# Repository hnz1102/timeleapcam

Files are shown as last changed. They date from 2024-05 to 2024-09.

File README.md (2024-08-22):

<div align="center">
  <h1><code>Time Leap Cam</code></h1>
  <p>
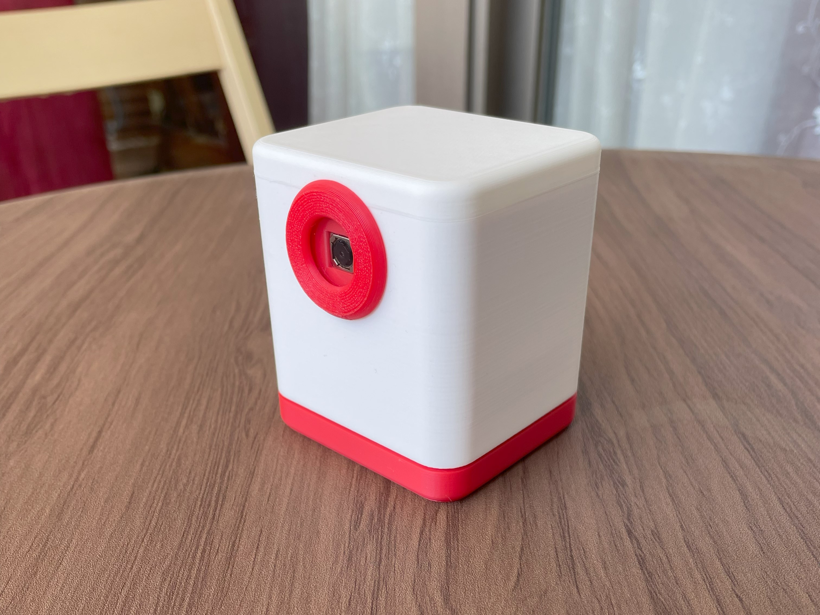
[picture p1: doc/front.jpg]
    
  </p>
</div>

# Time Leap Cam - Super Long Term Time-Lapse Camera and Monitoring by OpenAI

## Overview
The TIME LEAP CAM is an autofocus camera designed for long-duration time-lapse photography. Named for its ability to "leap" through time, this camera is ideal for monitoring over extended periods. It operates on battery power and features a DeepSleep mode to conserve energy when not actively shooting. Images are stored on a 64GB eMMC within one of eleven designated folders.

## What's New!
- 2024-08-12, If you want use on the XIAO ESP32S3 Sense module, please refer to the [XIAO_ESP32S3_SENSE branch](https://github.com/hnz1102/timeleapcam/tree/XIAO_ESP32S3_SENSE).
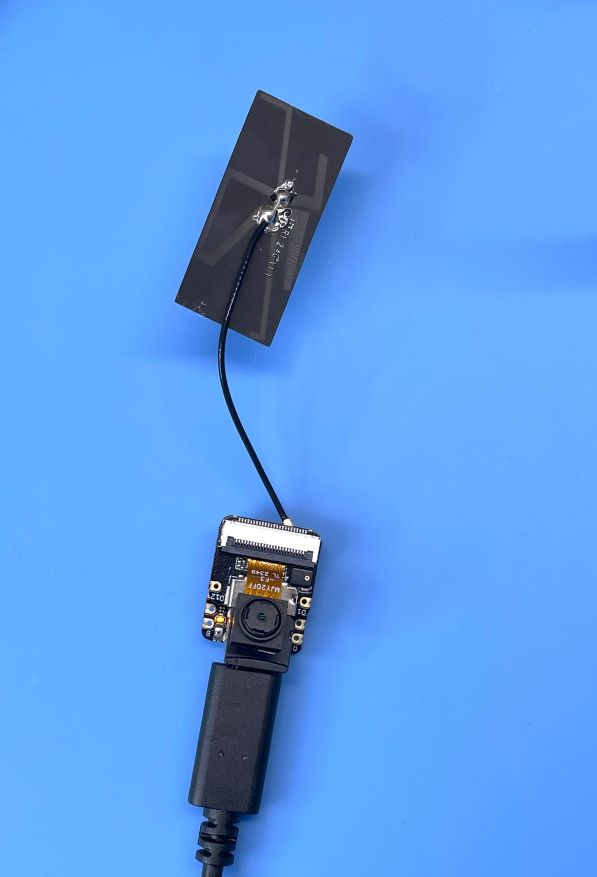
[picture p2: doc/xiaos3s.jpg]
XIAO_ESP32S3_SENSE


Update v0.3.3
- Improved the eMMC writing speed. The eMMC writing speed is improved by background writing. In the HD resolution, the writing speed is improved 28fps to 30fps. In the Full HD resolution, the writing speed is improved 6fps to 8fps. 
- JPEG quality can be set from 4 to 40. The default is 12. This value is high quality to set the value to 4. In the HD resolution, JPEG quality is set to less than 12, the writing speed is slower than 30fps. If you want to capture the image at 30fps, set the JPEG quality to 12 or more.
- If you want to direct write the image to the eMMC, set the 'Direct Write Mode' to checked. The image is directly written to the eMMC without the frame buffer. The writing speed is decreased. The default is unchecked.
- Changed the Allocate Unit Size to 32KB for the eMMC writing speed at the v0.3.3.

Update v0.3.2
- Add the 'System Temperature' to the status report. The temperature is measured by the internal temperature sensor of ESP32S3.
- Fixed the bug that when one-shot capture, the preview image is not displayed on the web.

Update v0.3.1
- Added the movie shooting function. The movie is created by combining the images taken at the specified cycle. 
 Capture Frames At Once (sec): The number of frames to capture at once. The default is 0, which means that the image is captured one by one. If you set it to 1, the image is captured during the 1 sec. If you set image resolution to VGA, the image is captured by 27 fps. HD is 15 - 27 fps. Full HD is 6 fps.
- Capture images are stored by appending the file. If you set to "Over Write Save", the image is overwritten. 
- Added the Open AI model 'GPT-4o mini' selection. The default is 'GPT-4o'. You can select the model from GPT-4o, GPT-4 Turbo, GPT-4o mini.
- If touch the button during 3 secs on the back, the camera starts the movie shooting. The movie shooting is stopped when the button is touched again.
- Improved the writing speed of the eMMC.
- Change the Report Interval: The default is 3600 sec. The report interval is changed to 3600 sec. The status report is sent to LINE when the specified cycle is reached.
- Camera interface is changed. Power Down, Reset pin is removed. In previous version, the power down pin and reset
pin are assigned by dumy GPIO pin. The 'esp-camera-rs' driver must be updated to the latest version.
- Fixed the bug that captured images are broken when the camera is in the DeepSleep mode. v0.3.1 is the stable version.
- Capturing clock is changed to 5MHz or 25MHz. The default is 5MHz when one image captured. When the movie is captured, the clock is changed to 25MHz.
- Changed the number of the frame buffer is 2. v0.3.0 set the number of the frame buffer to 3. But the eMMC writing speed is not enough to write the image to the eMMC. Since the eMMC writing speed is improved, the number of the frame buffer is changed to 2.
- Changed allocate_unit_size to 4096 for the eMMC writing speed at the v0.3.1.
- Fixed the bug that captured images are deleted when the camera is in the DeepSleep mode. v0.3.1 is fixed the bug.

Update v0.2.0
- Updated the UI for the configuration screen.
- Added the function to send a notification as status to LINE when the specified cycle is reached.
- Added the function to check the preview image on the web.
- Added images are uploaded to Cloudflare Images for private storage with signed URL.
- Added images are automatically deleted from the Cloudflare Images after 1 days.
- Added images can be downloaded as a compressed image from this camera on the web. (PC browser only)
- Added the function to check the remaining battery level on the web.
- Added the function to check the WiFi signal level on the web.
- Added the function to limit the time-lapse shooting time.
- Added the function to shoot when the camera touches the button during 3 secs on the back.

New Container Design
- The new container design is added for the camera
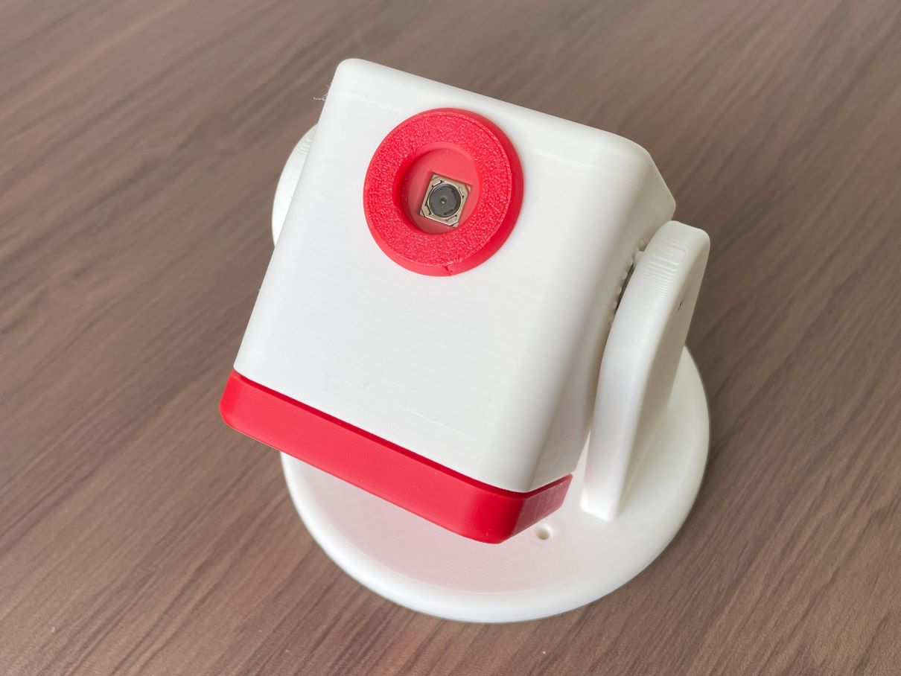
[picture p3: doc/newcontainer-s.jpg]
Container


## Features
- **Autofocus Capability**: Ensures clear images over long shooting intervals.
- **Energy Efficiency**: Utilizes DeepSleep mode for minimal power consumption (less than 440uA, 1.5mW).
- **Wireless Charging**: Supports Qi wireless charging and automatically stops charging when full.
- **Water Resistance**: Suitable for outdoor use with splash resistance.
- **Advanced Notifications**: Uses OpenAI's GPT-4o/GPT-4o mini for image recognition and sends notifications via LINE when specific conditions are met.
- **Natural Language Configuration**: Set notification conditions in multiple languages through a simple interface.
- **Touch-Activated Web Server**: Access settings via a browser with automatic return to sleep mode after 5 minutes of inactivity.
- **Time Synchronization**: Uses NTP for automatic time adjustment when connected to WiFi, with RTC to maintain time offline.

## Specification
- **Resolution**: Up to 2592x1944 (QSXGA)
- **Sensor**: OV5640 5M pixel sensor
- **SoC Module**: ESP32-S3-WROOM-1-N16R8 (160MHz, 512KB SRAM, 16MB Flash, 8MB PSRAM)
- **Battery**: 3.7V LiPo 1100mAh
- **Storage**: 64GB eMMC
- **Connectivity**: WiFi 2.4GHz
- **Charging**: Qi wireless charging compatible
- **Dimensions**: 78(W) x 79(H) x 68(D) mm Box

## Usage
To use the TIME LEAP CAM, place it on a Qi wireless charger to charge power. Configure the camera settings such as shooting interval, time, and resolution through a web browser connected via WiFi. The camera can be activated from sleep mode by touching the screw on the back, which launches the web server for configuration.

## Options
- **Folder Selection**: Choose from 11 different folders for storing images.
- **Image Resolution**: Selectable up to QSXGA (2592x1944).
- **Notification Conditions**: Set via natural language input on the configuration screen.

## Notes
- **Water Immersion**: The camera is not designed to withstand full submersion in water.
- **API Keys Required**: To use the image recognition and notification features, obtain API keys from OpenAI, CloudFlare Images, and LINE Messaging API.
- **Internet Connection**: Required for using advanced features like image recognition and notifications. Time-lapse functionality is available without WiFi.

For API keys and more information, visit:
- OpenAI API: [https://openai.com/index/openai-api/](https://openai.com/index/openai-api/)
- CloudFlare Images: [https://developers.cloudflare.com/images/about](https://developers.cloudflare.com/images/about)
- LINE Messaging API: [https://developers.line.biz/en/docs/messaging-api/](https://developers.line.biz/en/docs/messaging-api/)
# How to build from code and Install to the unit.

Using Ubuntu 22.04.3 LTS and ESP-IDF V5.2.1

## Prerequisites
Before proceeding with the installation, ensure that your system meets the following requirements:
- Operating System: Linux-based distribution
- Required Packages: git, python3, python3-pip, gcc, build-essential, curl, pkg-config, libudev-dev, libtinfo5, clang, libclang-dev, llvm-dev, udev, libssl-dev, python3.10-venv

## Installation Steps

### 1. System Update and Package Installation
Update your system and install the necessary packages using:
```bash
sudo apt update && sudo apt -y install git python3 python3-pip gcc build-essential curl pkg-config libudev-dev libtinfo5 clang libclang-dev llvm-dev udev libssl-dev python3.10-venv
```

### 2. Rust Installation
Install Rust programming language and Cargo package manager:
```bash
curl --proto '=https' --tlsv1.2 -sSf https://sh.rustup.rs | sh
```
After installation, activate Rust by sourcing the environment:
```bash
. "$HOME/.cargo/env"
```

### 3. Additional Tools Installation
Install the following Rust tools:
- ldproxy
- espup
- cargo-espflash

Use the following commands:
```bash
cargo install ldproxy
cargo install espup
cargo install cargo-espflash
```
2024-08-12, cargo-espflash can not be compiled.
If you have an error, use the following command.
```bash
cargo install cargo-binstall
cargo binstall cargo-espflash 
```

### 4. ESP Environment Setup
Run the following command to install and update the Espressif Rust ecosystem:
```bash
espup install
espup update
```
Set up environment variables:
```bash
. ./export-esp.sh
```

### 5. Udev Rules Configuration
Configure udev rules for device permissions:
```bash
sudo sh -c 'echo "SUBSYSTEMS==\"usb\", ATTRS{idVendor}==\"303a\", ATTRS{idProduct}==\"1001\", MODE=\"0666\"" > /etc/udev/rules.d/99-esp32.rules'
sudo udevadm control --reload-rules
sudo udevadm trigger
```

### 6. Clone Repository
Clone the TimeLeapCam repository:
```bash
git clone https://github.com/hnz1102/timeleapcam.git
cd timeleapcam/code/
```

### 7. Setting WiFi SSID, Password, etc.
Change the following the configuration file.
```bash
cfg.toml

[timeleapcam]
wifi_ssid = "<Your AP SSID>"  # Set your AP SSID
wifi_psk = "<Your AP Password>" # Set your AP Password
http_server = "" # NOT USED
resolution = "8"
track_id = "0"
timezone_offset = "9"
auto_capture = "false"
idle_in_sleep_time = "300"
duration = "0"
api_key = "<API KEY for openAI>" # Set your OpenAI API Key
model = "gpt-4o"
query_openai = "false"
query_prompt = "If heavy rain is expected in 30 minutes, please include a 'NOTICE' with the reason in your reply. If not, simply respond with 'NONE'. Heavy rain is defined as 30mm/h or more."
post_account = "<Your LINE Account ID>" # Set your LINE Account ID
post_access_token = "<Access Token for LINE Message>" # Set your LINE Access Token
storage_account = "<Your Cloudflare Account ID>" # Set your Cloudflare Account ID
storage_access_token = "<Your Cloudflare Access Token>" # Set your Cloudflare Access Token
storage_signed_key = "<Your Cloudflare Image Signed Key>" # Set your Cloudflare Image Signed Key
post_message_trigger = "NOTICE"
autofocus_once = "true"
status_report = "false"
status_report_interval = "3600"
post_interval = "3600"
leap_day = "-1"
leap_hour = "-1"
leap_minute = "-1"
capture_frames_at_once = "0"
overwrite_saved = "false"
```

### 8. Build and Flash
Build the project and flash it to your device:
```bash
cargo build --release
cargo espflash flash --release --monitor
```
At the first boot, the device will format the eMMC and create the necessary folders. This process may take a few minutes.

## Schematic, PCB Gabar and Container 3D Data

There is a Schematic data in the hardware directory including 3D printing data. 

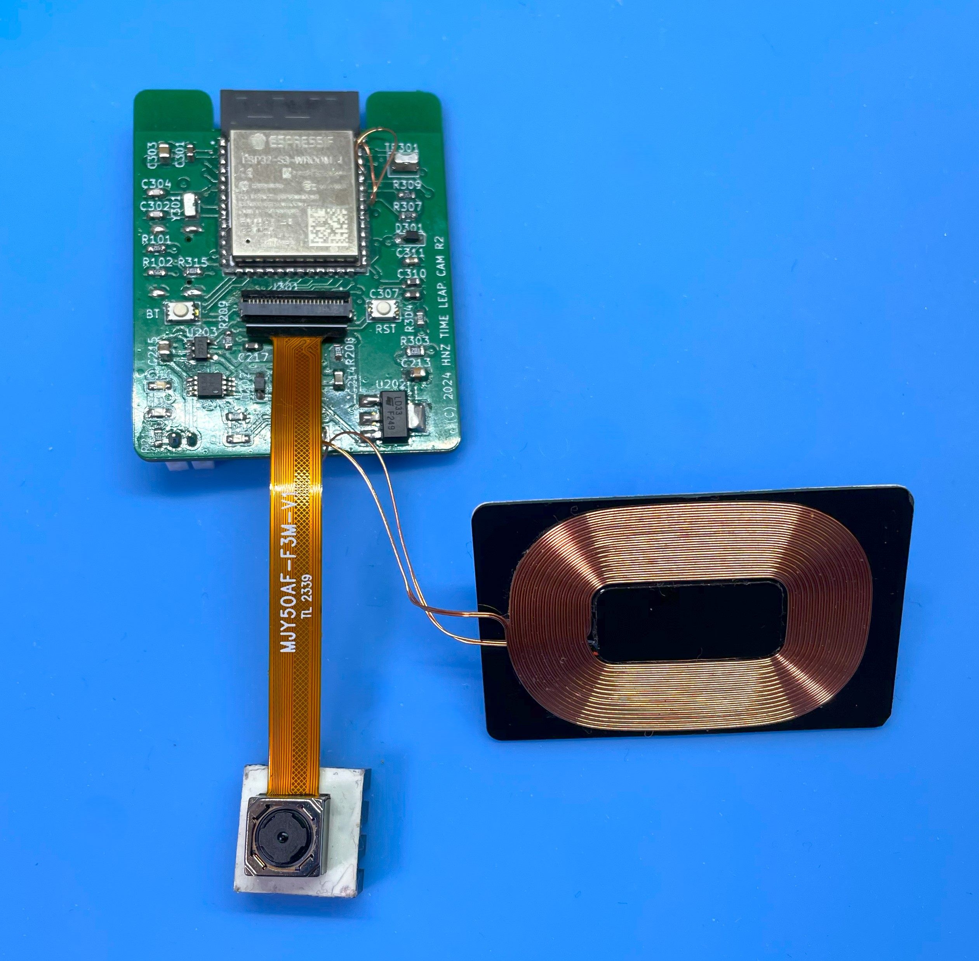
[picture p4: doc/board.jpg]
board


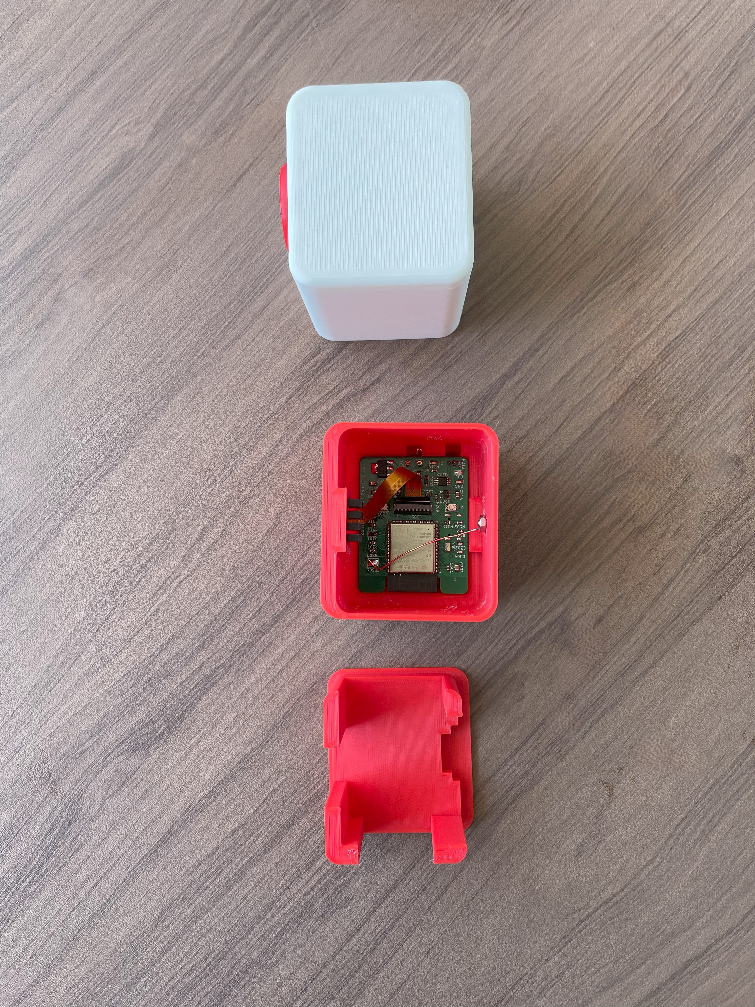
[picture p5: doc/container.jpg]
container


### New Cover and Base for the Camera
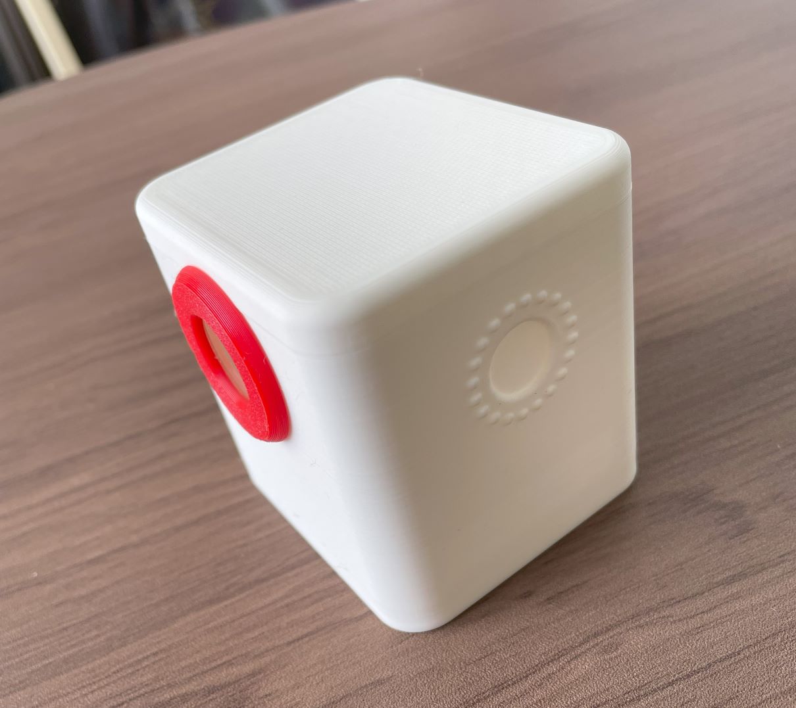
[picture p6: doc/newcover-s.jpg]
New-Cover


Base for the camera is also available for 3D printing. base-v14.stl is the latest version.
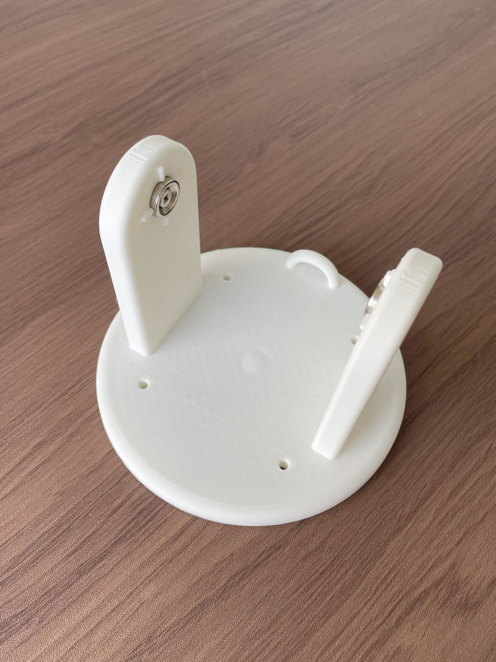
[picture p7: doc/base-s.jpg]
base


## Troubleshooting
- **Permission Issues**: Ensure udev rules are set correctly and you have the necessary permissions to access the device.
- **Build Errors**: Check that all dependencies are installed correctly. If errors persist, try cleaning the project with `cargo clean` and rebuild.

## LICENSE
This source code is licensed under MIT. Other Hardware Schematic documents are licensed under CC-BY-SA V4.0.

This project uses the following libraries and resources:
  
https://github.com/jlocash/esp-camera-rs

https://github.com/0015/ESP32-OV5640-AF

These libraries are licensed under each library's respective licenses.

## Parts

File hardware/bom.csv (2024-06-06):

Reference | Value | Datasheet | Footprint | Qty | DNP | digikey
C201,C207,C210 | 22nF/25V | ~ | Capacitor_SMD:C_0603_1608Metric | 3 |  | 490-17777-1-ND
C202,C208,C209 | 0.01uF/25V | ~ | Capacitor_SMD:C_0603_1608Metric | 3 |  | 311-1085-1-ND
C203,C217 | 0.1uF/25V | ~ | Capacitor_SMD:C_0603_1608Metric | 2 |  | 311-1343-1-ND
C204,C216,C218,C305,C306,C308,C309,C312,C313 | 1uF | ~ | Capacitor_SMD:C_0805_2012Metric | 9 |  | 311-1457-1-ND
C205 | 2000pF/25V | ~ | Capacitor_SMD:C_0603_1608Metric | 1 |  | 490-1458-1-ND
C206,C211 | 0.47uF/25V | ~ | Capacitor_SMD:C_0603_1608Metric | 2 |  | 445-5144-1-ND
C212,C301,C307,C310,C314,C315 | 0.1uF | ~ | Capacitor_SMD:C_0603_1608Metric | 6 |  | 311-1343-1-ND
C213,C303 | 10uF | ~ | Capacitor_SMD:C_0805_2012Metric | 2 |  | 1276-1096-1-ND
C214,C219 | 22uF | ~ | Capacitor_SMD:C_0805_2012Metric | 2 |  | 311-1903-1-ND
C215 | 4.7uF | ~ | Capacitor_SMD:C_0805_2012Metric | 1 |  | 1276-1244-1-ND
C302,C304 | 16pF | ~ | Capacitor_SMD:C_0603_1608Metric | 2 |  | 1292-1490-1-ND
C311 | 2.2uF | ~ | Capacitor_SMD:C_0603_1608Metric | 1 |  | 1276-1040-1-ND
D201,D203 | LED RED | ~ | LED_SMD:LED_0603_1608Metric_Pad1.05x0.95mm_HandSolder | 2 |  | 3147-B1931URO-20D000114U1930CT-ND
D202,D301 | NSR0340HT1G | https://www.onsemi.com/pub/Collateral/NSR0340H-D.PDF | Diode_SMD:D_SOD-323_HandSoldering | 2 |  | NSR0340HT1GOSCT-ND
D204 | LED GREEN | ~ | LED_SMD:LED_0603_1608Metric_Pad1.05x0.95mm_HandSolder | 1 |  | 3147-B1931NG--20D001114U1930CT-ND
FB101 | MH2029-601Y | ~ | Inductor_SMD:L_0805_2012Metric | 1 |  | MH2029-601YCT-ND
J101 | USB4105-GF-A | https://www.usb.org/sites/default/files/documents/usb_type-c.zip | tbctl:USB_C_5077CR-16-SMC2-BK-TR | 1 |  | 2073-USB4105-GF-ACT-ND
J201 | LiPo BATTERY | ~ | Connector_JST:JST_PH_B2B-PH-K_1x02_P2.00mm_Vertical | 1 |  | 455-1704-ND
J301 | FH34SRJ-24S-0.5SH50 | FH34SRJ-24S-0.5SH50 | tbctl:HRS_FH34SRJ-24S-0.5SH_50_ | 1 |  | 26-FH34SRJ-24S-0.5SH(50)CT-ND
L101 | WR483265-15F5-G | ~ | tbctl:PinHole_1x02_P4.5mm_Vertical | 1 |  | 445-16090-ND
Q201,Q202,Q203,Q301 | IRF7606TRPBF | http://www.irf.com/product-info/datasheets/data/irf7606pbf.pdf | Package_SO:MSOP-8_3x3mm_P0.65mm | 4 |  | IRF7606TRPBFCT-ND
R101,R102 | 5.1K | ~ | Resistor_SMD:R_0603_1608Metric | 2 |  | 311-5.1KGRCT-ND
R202,R303 | 1K | ~ | Resistor_SMD:R_0603_1608Metric | 2 |  | 311-1.00KHRCT-ND
R203,R208,R301,R302,R304,R308,R320,R321 | 10K | ~ | Resistor_SMD:R_0603_1608Metric | 8 |  | 13-RC0603JR-1010KLCT-ND
R204 | 110 1% | ~ | Resistor_SMD:R_0603_1608Metric | 1 |  | 13-RC0603FR-13110RLCT-ND
R207 | 150 1% | ~ | Resistor_SMD:R_0603_1608Metric | 1 |  | 13-RC0603FR-10150RLCT-ND
R209 | 2K | ~ | Resistor_SMD:R_0603_1608Metric | 1 |  | 311-2.0KGRCT-ND
R210,R310,R311,R312,R313,R314,R315,R316,R317,R318,R319 | 100K | ~ | Resistor_SMD:R_0603_1608Metric | 11 |  | 311-100KGRCT-ND
R211,R212 | 330 | ~ | Resistor_SMD:R_0603_1608Metric | 2 |  | 13-RC0603JR-13330RLCT-ND
R305,R306 | 51K 1% | ~ | Resistor_SMD:R_0603_1608Metric | 2 |  | 311-51.0KHRCT-ND
R307,R309 | 4.7K | ~ | Resistor_SMD:R_0603_1608Metric | 2 |  | 311-4.70KHRCT-ND
SW301,SW302 | 3.5x2.6 Tact SW |  | tbctl:WS-TASV SMT Tact Switch | 2 |  | 732-435151014824CT-ND
TP301 | TOUCHSW | ~ | tbctl:TestPoint_Pad_3.2x1.6mm | 1 |  | 2019-RCWCTECT-ND
U201 | BQ51013BRHLR | BQ51013BRHLR | RHL20_2P05X3P05 | 1 |  | 296-38885-1-ND
U202 | LDL1117S33TR_SOT223 | http://www.st.com/st-web-ui/static/active/en/resource/technical/document/datasheet/CD00000544.pdf | Package_TO_SOT_SMD:SOT-223-3_TabPin2 | 1 |  | 497-17239-1-ND
U203 | MCP73831-2-OT | http://ww1.microchip.com/downloads/en/DeviceDoc/20001984g.pdf | Package_TO_SOT_SMD:SOT-23-5 | 1 |  | MCP73831T-2ACI/OTCT-ND
U301 | ESP32-S3-WROOM-1-N16R8 | ESP32-S3-WROOM-1-N16R2 | ESP32-S3-WROOM-1_EXP | 1 |  | 1965-ESP32-S3-WROOM-1-N16R8CT-ND
U302 | MCP1700T-1502E/TT | http://ww1.microchip.com/downloads/en/DeviceDoc/20001826D.pdf | Package_TO_SOT_SMD:SOT-23 | 1 |  | MCP1700T-1502E/TTCT-ND
U303 | MCP1700T-2802E/TT | http://ww1.microchip.com/downloads/en/DeviceDoc/20001826D.pdf | Package_TO_SOT_SMD:SOT-23 | 1 |  | MCP1700T-2802E/TTCT-ND
U304 | FEMC064G-M11 |  | tbctl:EM32VSUKN FPGA153 | 1 |  | 3052-FEMC064G-M11-ND
Y301 | 32.7680KHz | ~ | Crystal:Crystal_SMD_3215-2Pin_3.2x1.5mm | 1 |  | 2151-RT3215-32.768-12.5-TRCT-ND

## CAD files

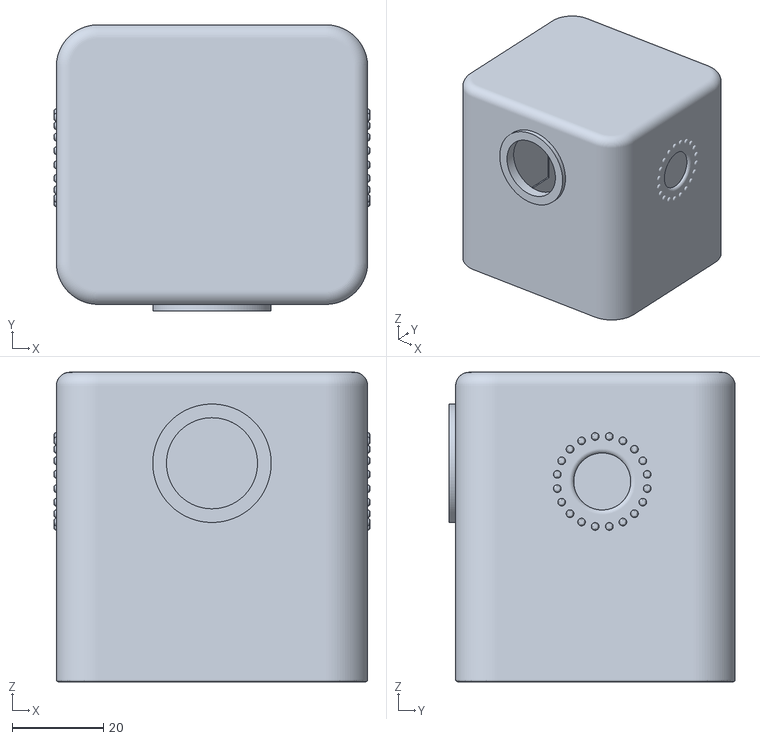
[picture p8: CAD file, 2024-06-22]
hardware/top-v15.stl
69.4 x 62.9 x 68.0

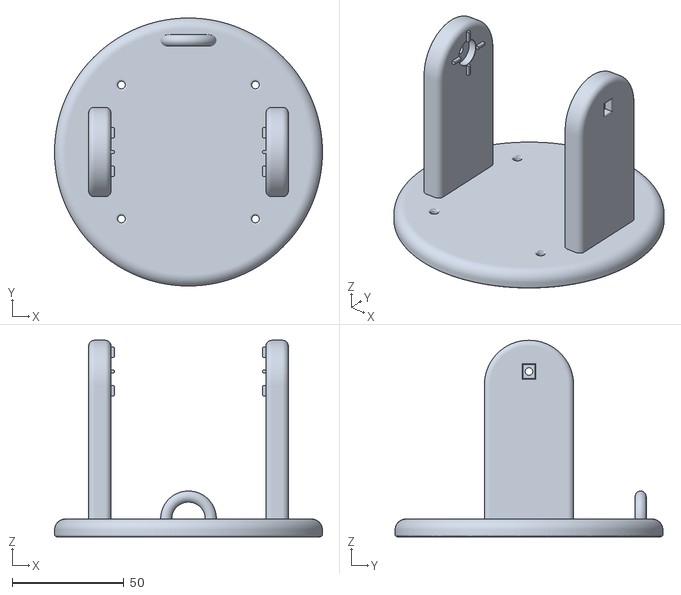
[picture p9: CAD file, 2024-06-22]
hardware/base-v14.stl
120.0 x 120.0 x 88.0

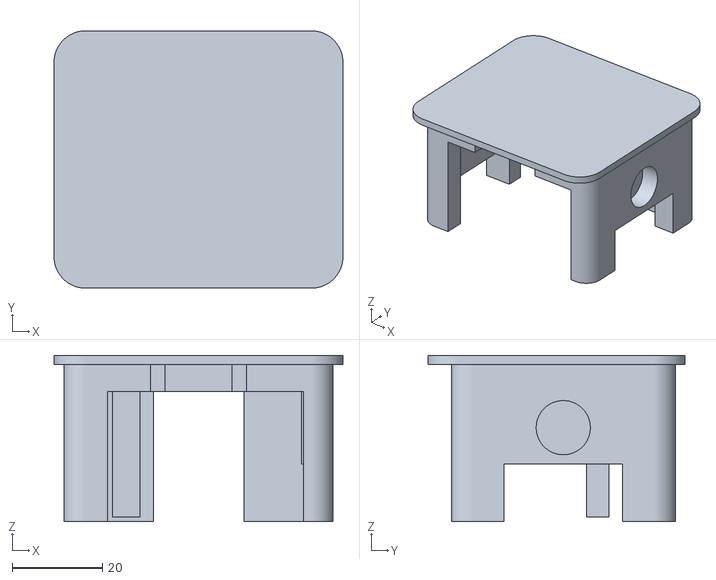
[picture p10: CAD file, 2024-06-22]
hardware/cap-v11.stl
64.0 x 57.0 x 36.8

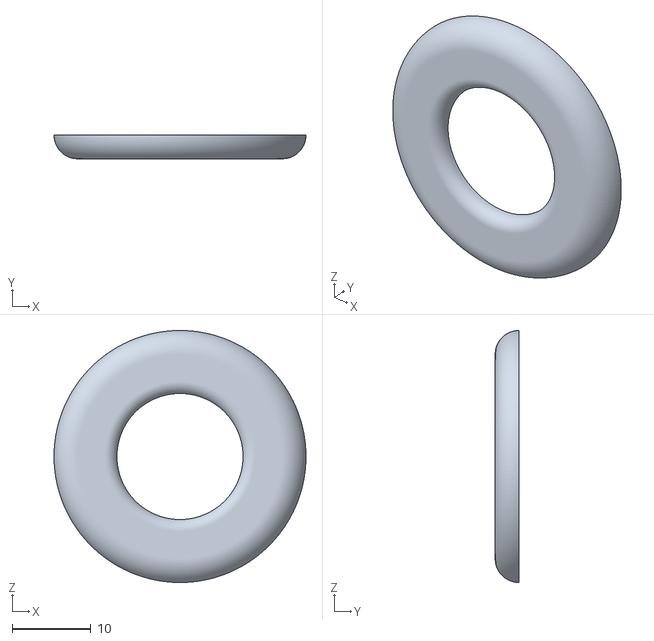
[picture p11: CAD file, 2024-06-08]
hardware/lensecap-v9.stl
32.0 x 3.00 x 32.0

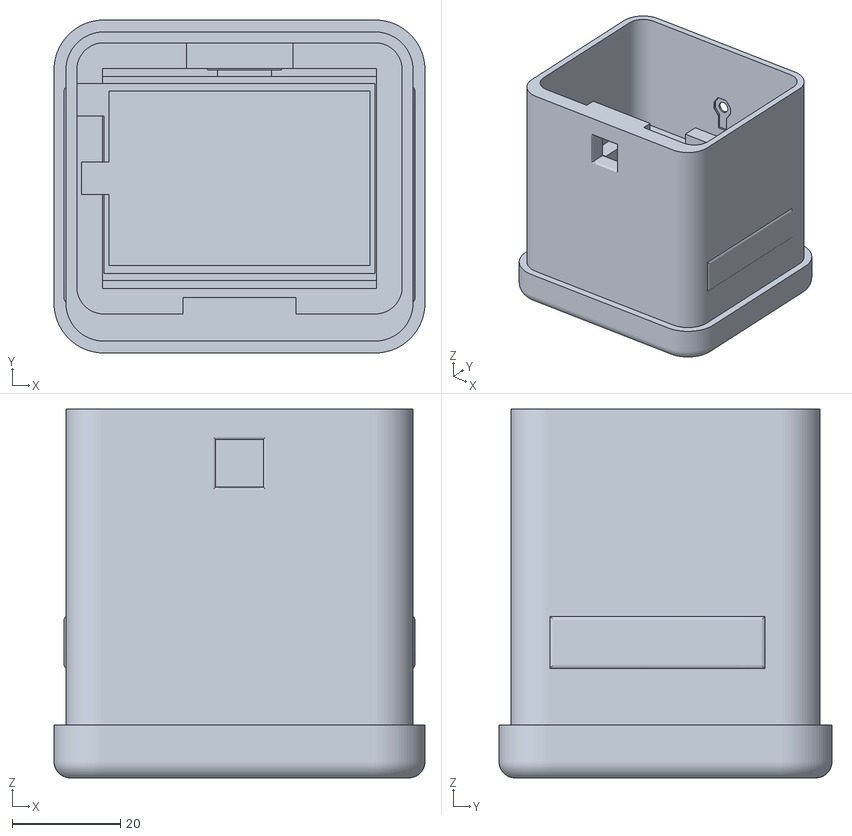
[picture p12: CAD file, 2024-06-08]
hardware/bottom-v9.stl
68.4 x 61.4 x 68.0

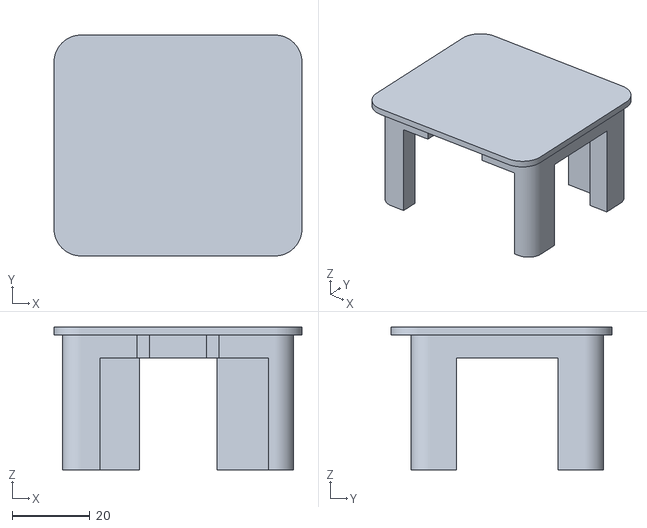
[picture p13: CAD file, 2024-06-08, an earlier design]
hardware/cap-v9.stl
64.0 x 57.0 x 36.8

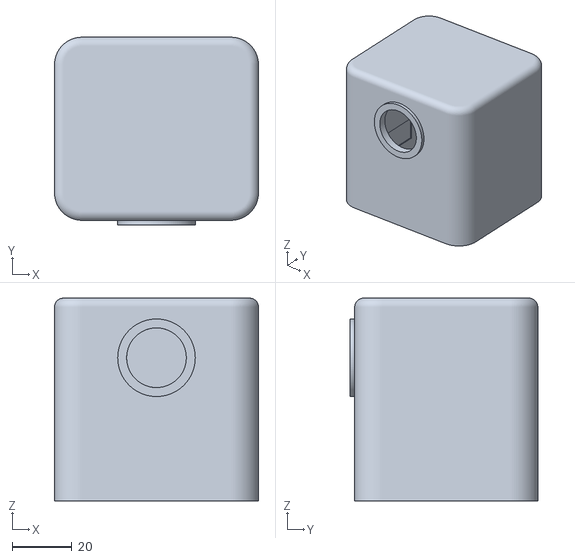
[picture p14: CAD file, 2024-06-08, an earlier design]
hardware/top-v9.stl
68.4 x 62.9 x 68.0

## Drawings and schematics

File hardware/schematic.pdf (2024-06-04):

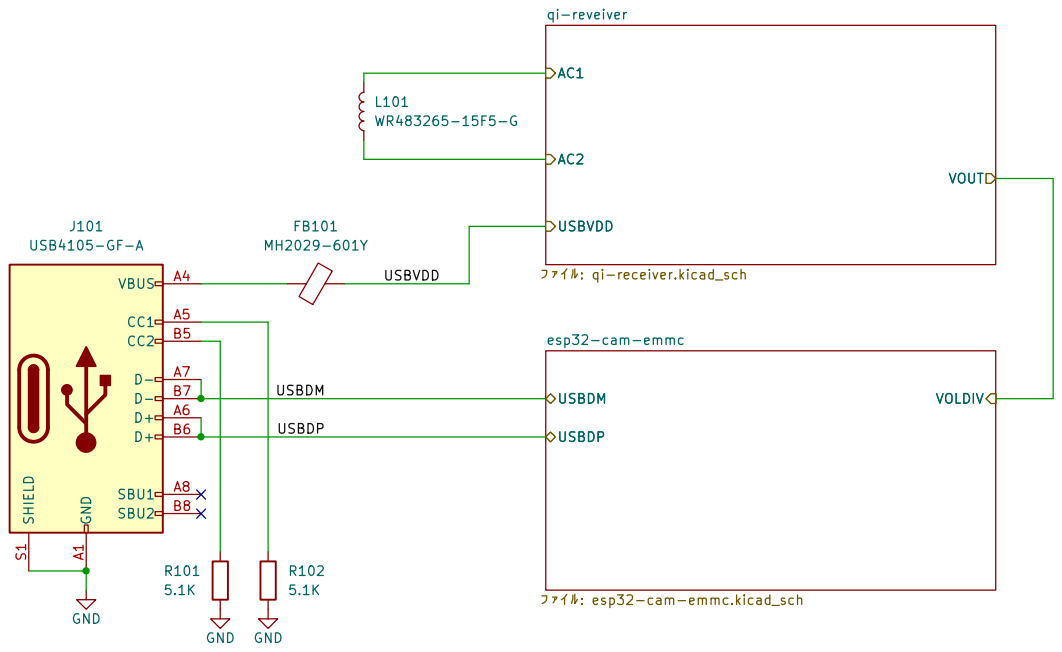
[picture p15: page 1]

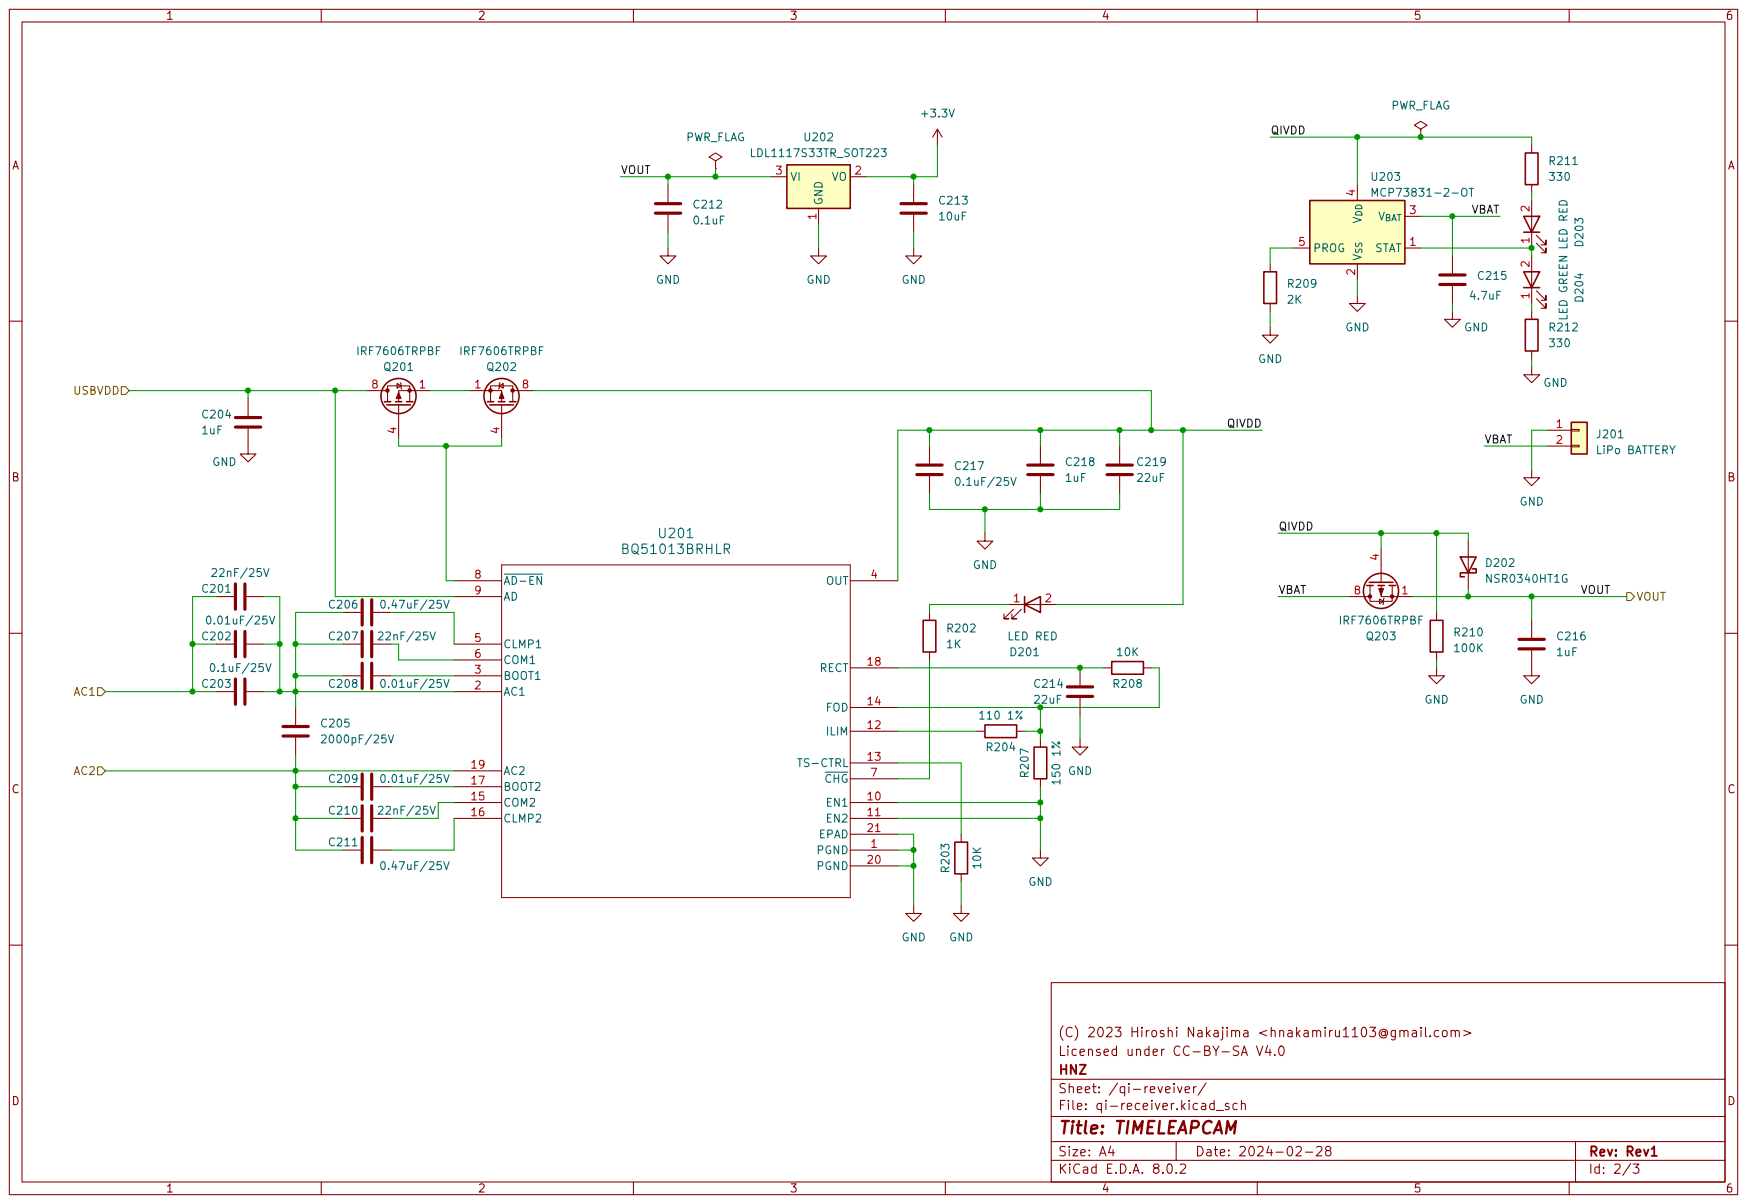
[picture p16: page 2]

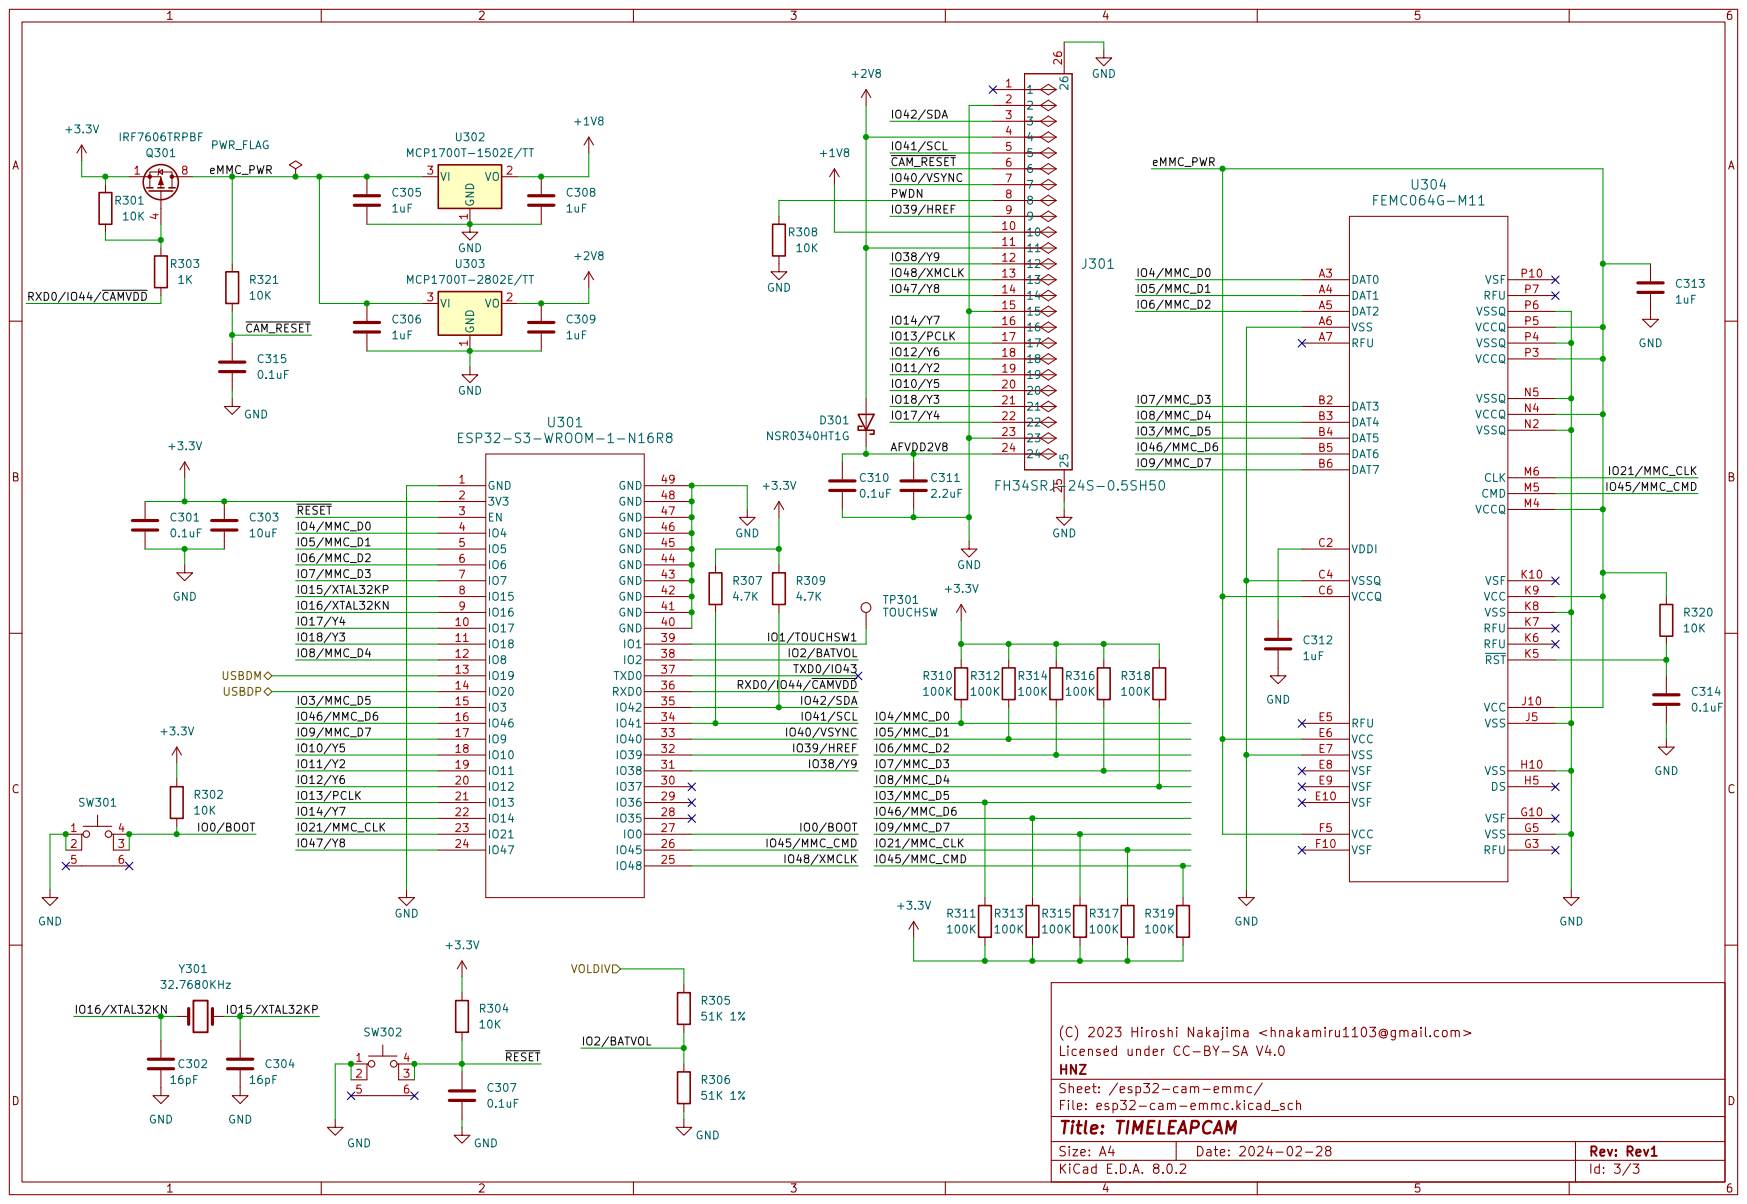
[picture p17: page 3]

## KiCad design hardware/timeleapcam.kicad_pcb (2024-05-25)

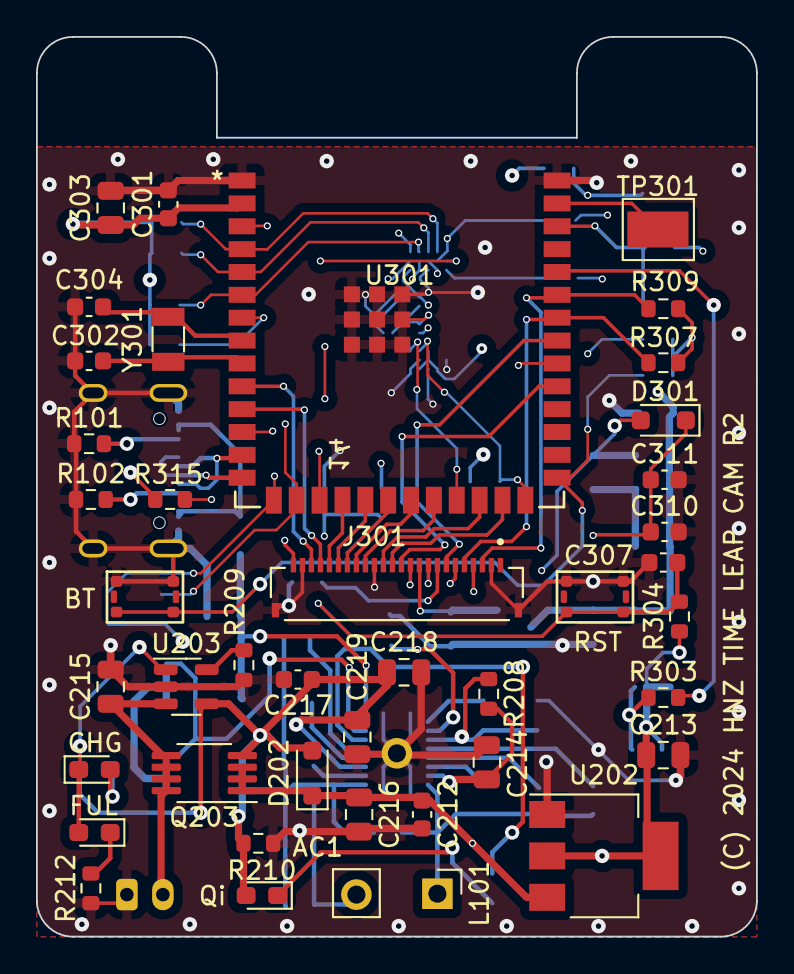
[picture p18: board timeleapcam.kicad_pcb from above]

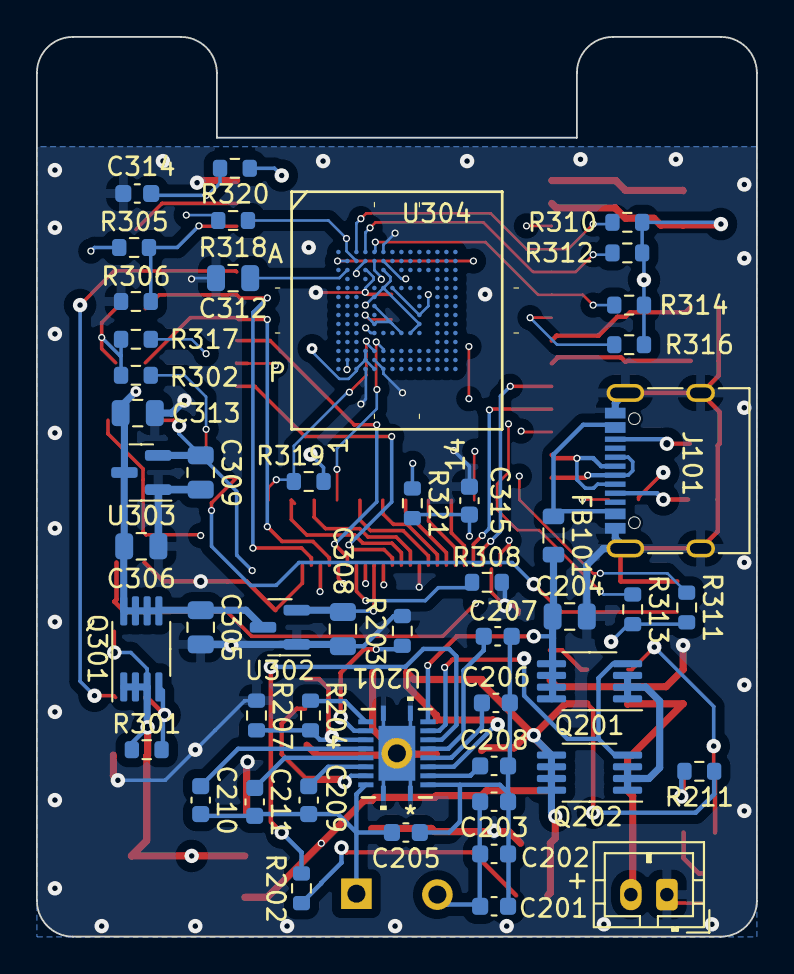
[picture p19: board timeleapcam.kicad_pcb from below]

Board: 4 copper layers, 40.0 x 50.0 mm, 91 parts (50 on the bottom side), 72 nets.

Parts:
C201, C207, C210: 22nF/25V; C_0603_1608Metric
C202, C208, C209: 0.01uF/25V; C_0603_1608Metric
C203, C217: 0.1uF/25V; C_0603_1608Metric
C204, C216, C218, C305, C306, C308, C309, C312, C313: 1uF; C_0805_2012Metric
C205: 2000pF/25V; C_0603_1608Metric
C206, C211: 0.47uF/25V; C_0603_1608Metric
C212, C301, C307, C310, C314, C315: 0.1uF; C_0603_1608Metric
C213, C303: 10uF; C_0805_2012Metric
C214, C219: 22uF; C_0805_2012Metric
C215: 4.7uF; C_0805_2012Metric
C302, C304: 16pF; C_0603_1608Metric
C311: 2.2uF; C_0603_1608Metric
D201, D203: LED RED; LED_0603_1608Metric_Pad1.05x0.95mm_HandSolder
D202, D301: NSR0340HT1G; D_SOD-323_HandSoldering
D204: LED GREEN; LED_0603_1608Metric_Pad1.05x0.95mm_HandSolder
FB101: MH2029-601Y; L_0805_2012Metric
J101: USB4105-GF-A; USB_C_5077CR-16-SMC2-BK-TR
J201: LiPo BATTERY; JST_PH_B2B-PH-K_1x02_P2.00mm_Vertical
J301: FH34SRJ-24S-0.5SH50; HRS_FH34SRJ-24S-0.5SH_50_
L101: WR483265-15F5-G; PinHole_1x02_P4.5mm_Vertical
Q201, Q202, Q203, Q301: IRF7606TRPBF; MSOP-8_3x3mm_P0.65mm
R101, R102: 5.1K; R_0603_1608Metric
R202, R303: 1K; R_0603_1608Metric
R203, R208, R301, R302, R304, R308, R310, R311, R312, R313, R314, R315, R316, R317, R318, R319, R320, R321: 10K; R_0603_1608Metric
R204: 110 1%; R_0603_1608Metric
R207: 150 1%; R_0603_1608Metric
R209: 2K; R_0603_1608Metric
R210: 100K; R_0603_1608Metric
R211, R212: 330; R_0603_1608Metric
R305, R306: 51K 1%; R_0603_1608Metric
R307, R309: 4.7K; R_0603_1608Metric
SW301, SW302: 3.5x2.6 Tact SW; WS-TASV SMT Tact Switch
TP301: TOUCHSW; TestPoint_Pad_3.2x1.6mm
U201: BQ51013BRHLR; RHL20_2P05X3P05
U202: LD1117S33TR_SOT223; SOT-223-3_TabPin2
U203: MCP73831-2-OT; SOT-23-5
U301: ESP32-S3-WROOM-1-N16R8; ESP32-S3-WROOM-1_EXP
U302: MCP1700T-1802E/TT; SOT-23
U303: MCP1700T-2802E/TT; SOT-23
U304: FEMC064G-M11; EM32VSUKN FPGA153
Y301: 32.7680KHz; Crystal_SMD_3215-2Pin_3.2x1.5mm

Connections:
+1V8: C308.1, J301.10, U302.2 (VO)
+2V8: C309.1, D301.2 (A), J301.4, J301.11, U303.2 (VO)
+3.3V: C213.1, C301.1, C303.1, Q301.1 (S), Q301.2 (S), Q301.3 (S), R301.1, R302.1, R304.1, R307.1, R309.1, R310.1, R311.2, R312.1, R313.2, R314.1, R315.2, R316.1, R317.2, R318.1, R319.2, U202.2 (VO), U301.2 (3V3)
/USBDM: J101.A7 (D-), J101.B7 (D-), U301.13 (IO19)
/USBDP: J101.A6 (D+), J101.B6 (D+), U301.14 (IO20)
/USBVDD: C204.1, FB101.2, Q201.5 (D), Q201.6 (D), Q201.7 (D), Q201.8 (D), U201.9 (AD)
/esp32-cam-emmc/AFVDD2V8: C310.1, C311.1, D301.1 (K), J301.24
/esp32-cam-emmc/IO0/BOOT: R302.2, SW301.3 (K), SW301.4 (A), U301.27 (IO0)
/esp32-cam-emmc/IO1/TOUCHSW1: TP301.1, U301.39 (IO1)
/esp32-cam-emmc/IO2/BATVOL: R305.2, R306.1, U301.38 (IO2)
/esp32-cam-emmc/IO3/MMC_D5: R311.1, U301.15 (IO3), U304.B4 (DAT5)
/esp32-cam-emmc/IO4/MMC_D0: R310.2, U301.4 (IO4), U304.A3 (DAT0)
/esp32-cam-emmc/IO5/MMC_D1: R312.2, U301.5 (IO5), U304.A4 (DAT1)
/esp32-cam-emmc/IO6/MMC_D2: R314.2, U301.6 (IO6), U304.A5 (DAT2)
/esp32-cam-emmc/IO7/MMC_D3: R316.2, U301.7 (IO7), U304.B2 (DAT3)
/esp32-cam-emmc/IO8/MMC_D4: R318.2, U301.12 (IO8), U304.B3 (DAT4)
/esp32-cam-emmc/IO9/MMC_D7: R315.1, U301.17 (IO9), U304.B6 (DAT7)
/esp32-cam-emmc/IO10/Y5: J301.20, U301.18 (IO10)
/esp32-cam-emmc/IO11/Y2: J301.19, U301.19 (IO11)
/esp32-cam-emmc/IO12/Y6: J301.18, U301.20 (IO12)
/esp32-cam-emmc/IO13/PCLK: J301.17, U301.21 (IO13)
/esp32-cam-emmc/IO14/Y7: J301.16, U301.22 (IO14)
/esp32-cam-emmc/IO15/XTAL32KP: C304.1, U301.8 (IO15), Y301.2
/esp32-cam-emmc/IO16/XTAL32KN: C302.1, U301.9 (IO16), Y301.1
/esp32-cam-emmc/IO17/Y4: J301.22, U301.10 (IO17)
/esp32-cam-emmc/IO18/Y3: J301.21, U301.11 (IO18)
/esp32-cam-emmc/IO21/MMC_CLK: R317.1, U301.23 (IO21), U304.M6 (CLK)
/esp32-cam-emmc/IO38/Y9: J301.12, U301.31 (IO38)
/esp32-cam-emmc/IO39/HREF: J301.9, U301.32 (IO39)
/esp32-cam-emmc/IO40/VSYNC: J301.7, U301.33 (IO40)
/esp32-cam-emmc/IO41/SCL: J301.5, R307.2, U301.34 (IO41)
/esp32-cam-emmc/IO42/SDA: J301.3, R309.2, U301.35 (IO42)
/esp32-cam-emmc/IO45/MMC_CMD: R319.1, U301.26 (IO45), U304.M5 (CMD)
/esp32-cam-emmc/IO46/MMC_D6: R313.1, U301.16 (IO46), U304.B5 (DAT6)
/esp32-cam-emmc/IO47/Y8: J301.14, U301.24 (IO47)
/esp32-cam-emmc/IO48/XMCLK: J301.13, U301.25 (IO48)
/esp32-cam-emmc/PWDN: J301.8, R308.1
/esp32-cam-emmc/RXD0/IO44/~CAMVDD: R303.2, U301.36 (RXD0)
/esp32-cam-emmc/eMMC_PWR: C305.1, C306.1, C313.1, Q301.5 (D), Q301.6 (D), Q301.7 (D), Q301.8 (D), R320.1, R321.1, U302.3 (VI), U303.3 (VI), U304.C6 (VCCQ), U304.E6 (VCC), U304.F5 (VCC), U304.J10 (VCC), U304.K9 (VCC), U304.M4 (VCCQ), U304.N4 (VCCQ), U304.P3 (VCCQ), U304.P5 (VCCQ)
/esp32-cam-emmc/~CAM_RESET: C315.1, J301.6, R321.2
/esp32-cam-emmc/~RESET: C307.1, R304.2, SW302.3 (K), SW302.4 (A), U301.3 (EN)
/qi-reveiver/AC1: C201.2, C202.2, C203.2, L101.2
/qi-reveiver/AC2: C205.2, C209.2, C210.2, C211.2, L101.1, U201.19 (AC2)
/qi-reveiver/QIVDD: C217.1, C218.1, C219.1, D201.2 (A), D202.2 (A), Q202.5 (D), Q202.6 (D), Q202.7 (D), Q202.8 (D), Q203.4 (G), R210.1, R211.1, U201.4 (OUT), U203.4 (V_{DD})
/qi-reveiver/VBAT: C215.1, J201.2, Q203.5 (D), Q203.6 (D), Q203.7 (D), Q203.8 (D), U203.3 (V_{BAT})
/qi-reveiver/VOUT: C212.1, C216.1, D202.1 (K), Q203.1 (S), Q203.2 (S), Q203.3 (S), R305.1, U202.3 (VI)
GND: C204.2, C212.2, C213.2, C214.2, C215.2, C216.2, C217.2, C218.2, C219.2, C301.2, C302.2, C303.2, C304.2, C305.2, C306.2, C307.2, C308.2, C309.2, C310.2, C311.2, C312.2, C313.2, C314.2, C315.2, J101.A1 (GND), J101.A12 (GND), J101.B1 (GND), J101.B12 (GND), J101.S1 (SHIELD), J201.1, J301.2, J301.15, J301.23, J301.25, J301.26, R101.1, R102.1, R203.1, R207.1, R209.2, R210.2, R212.2, R306.2, R308.2, SW301.1, SW301.2, SW302.1, SW302.2, U201.1 (PGND), U201.10 (EN1), U201.11 (EN2), U201.20 (PGND), U201.21 (EPAD), U202.1 (GND), U203.2 (V_{SS}), U301.1 (GND), U301.40 (GND), U301.41 (GND), U301.42 (GND), U301.43 (GND), U301.44 (GND), U301.45 (GND), U301.46 (GND), U301.47 (GND), U301.48 (GND), U301.49 (GND), U302.1 (GND), U303.1 (GND), U304.A6 (VSS), U304.C4 (VSSQ), U304.E7 (VSS), U304.G5 (VSS), U304.H10 (VSS), U304.J5 (VSS), U304.K8 (VSS), U304.N2 (VSSQ), U304.N5 (VSSQ), U304.P4 (VSSQ), U304.P6 (VSSQ)
unnamed: D201.1 (K), R202.1
unnamed: D203.2 (A), R211.2
unnamed: D203.1 (K), D204.2 (A), U203.1 (STAT)
unnamed: D204.1 (K), R212.1
unnamed: FB101.1, J101.A4 (VBUS), J101.A9 (VBUS), J101.B4 (VBUS), J101.B9 (VBUS)
unnamed: J101.A5 (CC1), R102.2
unnamed: J101.B5 (CC2), R101.2
unnamed: Q201.4 (G), Q202.4 (G), U201.8 (~AD-EN)
unnamed: Q201.1 (S), Q201.2 (S), Q201.3 (S), Q202.1 (S), Q202.2 (S), Q202.3 (S)
unnamed: Q301.4 (G), R301.2, R303.1
unnamed: C201.1, C202.1, C203.1, C205.1, C206.2, C207.2, C208.2, U201.2 (AC1)
unnamed: C208.1, U201.3 (BOOT1)
unnamed: C209.1, U201.17 (BOOT2)
unnamed: C206.1, U201.5 (CLMP1)
unnamed: C211.1, U201.16 (CLMP2)
unnamed: C207.1, U201.6 (COM1)
unnamed: C210.1, U201.15 (COM2)
unnamed: R204.1, R207.2, R208.1, U201.14 (FOD)
unnamed: R204.2, U201.12 (ILIM)
unnamed: C214.1, R208.2, U201.18 (RECT)
unnamed: R203.2, U201.13 (TS-CTRL)
unnamed: R202.2, U201.7 (~CHG)
unnamed: R209.1, U203.5 (PROG)
unnamed: C312.1, U304.C2 (VDDI)
unnamed: C314.1, R320.2, U304.K5 (~RST)

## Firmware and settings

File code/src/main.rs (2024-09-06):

#![allow(dead_code, unused_imports)]

use anyhow;
use std::{thread, time::Duration};
use esp_camera_rs::Camera;
use esp_idf_hal::peripherals::Peripherals;
use esp_idf_hal::gpio::{PinDriver, Gpio2};
use esp_idf_svc::wifi::EspWifi;
use esp_idf_sys::camera;
use log::info;
use std::net::Ipv4Addr;

use esp_idf_svc::nvs::{EspNvsPartition, NvsDefault, EspNvs, NvsPartitionId};
use esp_idf_svc::sntp::{EspSntp, SyncStatus, SntpConf, OperatingMode, SyncMode};
use esp_idf_hal::adc::{config::Config as AdcConfig, AdcChannelDriver, AdcDriver};
use std::time::{SystemTime, UNIX_EPOCH};
use chrono::{DateTime, Utc};
use chrono::{Local, Duration as ChronoDuration, FixedOffset, NaiveDate, Datelike, Timelike};

mod wifi;
mod capture;
mod autofocus;
mod emmc;
mod imagefiles;
mod server;
mod config;
mod touchpad;
mod monitoring;

use touchpad::{TouchPad, KeyEvent, Key};
use config::ConfigData;
use capture::Capture;
use emmc::EMMCHost;
use server::LeapTime;
use monitoring::Monitoring;

#[derive(PartialEq)]
enum SleepMode {
    SleepModeLight,
    SleepModeDeep,
}

const MAX_NVS_STR_SIZE : usize = 3072;

#[link_section = ".rtc.data"]
static mut IMAGE_COUNT_ID: u32 = 0;

#[link_section = ".rtc.data"]
static mut DEEP_SLEEP_AUTO_CAPTURE: bool = false;

#[link_section = ".rtc.data"]
static mut NEXT_CAPTURE_TIME: u64 = 0;

#[link_section = ".rtc.data"]
static mut DURATION_TIME: u32 = 0;

#[link_section = ".rtc.data"]
static mut CURRENT_RESOLUTION: u32 = 0;

#[link_section = ".rtc.data"]
static mut CURRENT_TRACK_ID: u32 = 0;

#[link_section = ".rtc.data"]
static mut LAST_CAPTURE_TIME: u64 = 0;

#[link_section = ".rtc.data"]
static mut LAST_POSTED_TIME: u64 = 0;

#[link_section = ".rtc.data"]
static mut CAPTURE_START_TIME: u64 = 0;

#[link_section = ".rtc.data"]
static mut CAPTURE_END_TIME: u64 = 0;

#[link_section = ".rtc.data"]
static mut LAST_STATUS_POSTED_TIME: u64 = 0;

fn main() -> anyhow::Result<()> {
    esp_idf_svc::sys::link_patches();
    esp_idf_svc::log::EspLogger::initialize_default();

    // Peripherals Initialize
    let peripherals = Peripherals::take().unwrap();

    // eMMC and Camera Power On (low active)
    let mut emmc_cam_power = PinDriver::output(peripherals.pins.gpio44).unwrap();
    emmc_cam_power.set_low().expect("Set emmc_cam_power low failure");

    // TouchPad
    let mut touchpad = TouchPad::new();
    touchpad.start();
    thread::sleep(Duration::from_millis(1000));

    // operating mode
    let mut operating_mode = false;

    // wakeup reason
    let wakeup_reason : u32;
    unsafe {
        wakeup_reason = esp_idf_sys::esp_sleep_get_wakeup_cause();
        info!("Wakeup reason: {:?}", wakeup_reason);
        match wakeup_reason {
            esp_idf_sys::esp_sleep_source_t_ESP_SLEEP_WAKEUP_TOUCHPAD => {
                operating_mode = true;
                info!("Wakeup by touchpad");
            },
            esp_idf_sys::esp_sleep_source_t_ESP_SLEEP_WAKEUP_TIMER => {
                info!("Wakeup by timer");
            },
            esp_idf_sys::esp_sleep_source_t_ESP_SLEEP_WAKEUP_UNDEFINED => {
                info!("Power ON boot");
                if touchpad.get_touchpad_status(Key::Center) {
                    info!("Erase NVS flash...");
                    esp_idf_sys::nvs_flash_erase();
                    thread::sleep(Duration::from_millis(1000));
                }    
                esp_idf_sys::nvs_flash_init();
                operating_mode = true;
            },
            _ => {
                info!("Wakeup by Unknown");
            }
        }
    }
    // Initialize Configuration Data
    let mut config_data = ConfigData::new();

    // Initialize NVS
    let nvs_default_partition = EspNvsPartition::<NvsDefault>::take().unwrap();
    let mut nvs = match EspNvs::new(nvs_default_partition, "storage", true) {
        Ok(nvs) => { info!("NVS storage area initialized"); nvs },
        Err(ref e) => {
            panic!("NVS initialization failed {:?}", e); }
    };

    // Load config
    let mut nvs_buf : [u8 ; MAX_NVS_STR_SIZE] = [0; MAX_NVS_STR_SIZE];
    let nvs_value = match nvs.get_str("config", &mut nvs_buf){
        Ok(value) => { info!("Try to read NVS config"); value },
        Err(ref e) => { info!("NVS config not found {:?}", e); None }
    };
    if nvs_value == None {
        info!("NVS config not found. Set default config");
        set_default_config(&mut config_data, &mut nvs);
        thread::sleep(Duration::from_millis(1000));
    }
    else {
        // info!("NVS config found {:?}", nvs_value);
        match config_data.load_config(nvs_value) {
            Ok(_) => { info!("Config load success"); },
            Err(ref e) => { 
                info!("Config load failed {:?}", e);
                set_default_config(&mut config_data, &mut nvs);
                thread::sleep(Duration::from_millis(1000));
            },
        }    
    }

    // Initialize Temperature Sensor
    let mut config = esp_idf_svc::hal::sys::temperature_sensor_config_t::default();
    let mut temp_sensor_ptr : *mut esp_idf_svc::sys::temperature_sensor_obj_t =
             std::ptr::null_mut() as *mut esp_idf_svc::sys::temperature_sensor_obj_t;
    unsafe {
        esp_idf_svc::hal::sys::temperature_sensor_install(&mut config, &mut temp_sensor_ptr);
        esp_idf_svc::hal::sys::temperature_sensor_enable(&mut *temp_sensor_ptr);
    }

    // Initialize ADC
    let mut adc = AdcDriver::new(peripherals.adc1, &AdcConfig::new().calibration(true))?;
    let mut adc_pin : AdcChannelDriver<'_, {esp_idf_sys::adc_atten_t_ADC_ATTEN_DB_11}, Gpio2> = AdcChannelDriver::new(peripherals.pins.gpio2)?;
    let battery_voltage : f32 =  adc.read(&mut adc_pin).unwrap() as f32 * 2.0 / 1000.0;
    info!("Battery Voltage: {:.2}V", battery_voltage);
    // emmc initialize
    let mut emmc = EMMCHost::new();
    let mut mount_retry = 0;
    loop {
        match emmc.mount() {
            Ok(_) => { info!("eMMC/SDCard mounted");
                break;
            },
            Err(e) => {
                // format eMMC
                emmc.format();
                info!("eMMC/SDCard mount failed {:?}", e);
                mount_retry += 1;
                if mount_retry > 3 {
                    info!("eMMC/SDCard mount failed.");
                    break;
                }
            }
        }
        thread::sleep(Duration::from_millis(100));
    }
    // emmc.format();
    // imagefiles::delete_all_files(Path::new("/eMMC"));

    let mut server_info = server::ControlServerInfo::new();
    // config_data
    // info!("Start config_data: {:?}", config_data);
    info!("Auto Capture: {:?}", unsafe { DEEP_SLEEP_AUTO_CAPTURE } );
    info!("Image Count ID: {:?}", unsafe { IMAGE_COUNT_ID });

    let mut current_resolution = camera::framesize_t_FRAMESIZE_QSXGA;
    if operating_mode {
        // operating mode
        server_info.duration = config_data.duration;
        server_info.resolution = config_data.resolution;
        server_info.track_id = config_data.track_id;
    }
    else {
        // wakeup
        server_info.duration = unsafe { DURATION_TIME };
        server_info.resolution = unsafe { CURRENT_RESOLUTION };
        server_info.track_id = unsafe { CURRENT_TRACK_ID };
        current_resolution = server_info.resolution;

    }
    server_info.auto_capture = config_data.auto_capture;
    server_info.idle_in_sleep_time = config_data.idle_in_sleep_time;
    server_info.timezone = config_data.timezone_offset;
    server_info.autofocus_once = config_data.autofocus_once;
    server_info.last_capture_date_time = SystemTime::UNIX_EPOCH + Duration::from_secs(unsafe { LAST_CAPTURE_TIME });
    server_info.last_posted_date_time = SystemTime::UNIX_EPOCH + Duration::from_secs(unsafe { LAST_POSTED_TIME });
    server_info.capture_start_time = SystemTime::UNIX_EPOCH + Duration::from_secs(unsafe { CAPTURE_START_TIME });
    server_info.capture_end_time = SystemTime::UNIX_EPOCH + Duration::from_secs(unsafe { CAPTURE_END_TIME });    
    server_info.query_prompt = config_data.query_prompt.clone();
    server_info.query_openai = config_data.query_openai;
    server_info.openai_model = config_data.model.clone();
    server_info.status_report = config_data.status_report;
    server_info.status_report_interval = config_data.status_report_interval;
    server_info.post_interval = config_data.post_interval;
    server_info.capture_frames_at_once = config_data.capture_frames_at_once;
    server_info.jpeg_quality = config_data.jpeg_quality;
    server_info.overwrite_saved = config_data.overwrite_saved;
    server_info.direct_write_mode = config_data.direct_write_mode;
    let mut last_status_posted_time = SystemTime::UNIX_EPOCH + Duration::from_secs(unsafe { LAST_STATUS_POSTED_TIME });
    let mut next_capture_time = UNIX_EPOCH + Duration::from_secs(unsafe { NEXT_CAPTURE_TIME });
    let mut capture_id = unsafe { IMAGE_COUNT_ID };
    let mut current_track_id = server_info.track_id;
    let mut current_duration = server_info.duration;
    let dt_utc : DateTime<Utc> = DateTime::<Utc>::from(next_capture_time);
    let fixed_offset = FixedOffset::east_opt(config_data.timezone_offset * 3600).unwrap();
    let dt_local = DateTime::<Local>::from_naive_utc_and_offset(dt_utc.naive_utc(), fixed_offset);
    info!("Next Capture Time: {} Capture Count: {}", dt_local.format("%Y-%m-%d %H:%M:%S"), capture_id);

    let status_post_need = server_info.status_report && (capture_id % server_info.status_report_interval) == 0;
    // current_settings into server_info
    server_info.leap_time = LeapTime {
        year: -1,
        month: -1,
        day: config_data.leap_day,
        hour: config_data.leap_hour,
        minute: config_data.leap_minute,
        second: 0,
    };

    // wifi initialize
    let mut wifi_dev : Result<Box<EspWifi>, anyhow::Error> = Result::Err(anyhow::anyhow!("WiFi not connected"));
    let mut server_enabled = false;
    let mut server : Option<server::ControlServer> = match operating_mode || config_data.query_openai || status_post_need {
        true => {
            wifi_dev = wifi::wifi_connect(peripherals.modem, &config_data.wifi_ssid, &config_data.wifi_psk);
            match &wifi_dev {
                Ok(_) => { 
                    info!("WiFi connected"); 
                    let rssi = wifi::get_rssi();
                    info!("RSSI: {}dBm", rssi);
                    if rssi != 0 {
                        // ssid
                        let ssid = config_data.wifi_ssid.clone();
                        info!("Connected SSID: {:?}", ssid);
                        // Get my IP address
                        let mut ip_addr : Ipv4Addr; 
                        loop {
                            ip_addr = wifi_dev.as_ref().unwrap().sta_netif().get_ip_info().unwrap().ip;
                            if ip_addr != Ipv4Addr::new(0, 0, 0, 0) {
                                break;
                            }
                            info!("Waiting for WiFi connection...");
                            thread::sleep(Duration::from_secs(1));
                        }
                        info!("My IP address: {}", ip_addr);
                        
                        // NTP Server
                        let sntp_conf = SntpConf {
                            servers: ["time.aws.com",
                                        "time.google.com",
                                        "time.cloudflare.com",
                                        "ntp.nict.jp"],
                            operating_mode: OperatingMode::Poll,
                            sync_mode: SyncMode::Immediate,
                        };
                        let ntp = EspSntp::new(&sntp_conf).unwrap();
            
                        // NTP Sync
                        // let now = SystemTime::now();
                        // if now.duration_since(UNIX_EPOCH).unwrap().as_millis() < 1700000000 {
                        info!("NTP Sync Start..");
                        // wait for sync
                        while ntp.get_sync_status() != SyncStatus::Completed {
                            thread::sleep(Duration::from_millis(10));
                        }
                        let now = SystemTime::now();
                        let dt_now : DateTime<Utc> = now.into();
                        let formatted = format!("{}", dt_now.format("%Y-%m-%d %H:%M:%S"));
                        info!("NTP Sync Completed: {}", formatted);
            
                        // HTTP Server
                        let mut server = match server::ControlServer::new(&server_info) {
                            Ok(server_ctx) => {
                                info!("HTTP Server started");
                                server_ctx
                            }
                            Err(e) => {
                                info!("Failed to start HTTP Server: {:?}", e);
                                return Result::Err(anyhow::anyhow!("Failed to start HTTP Server"));
                            }
                        };
                        server.start();
                        server_enabled = true;        
                        Some(server)
                    }
                    else {
                        info!("WiFi not connected");
                        None
                    }
                },
                Err(ref e) => {
                    info!("{:?}", e);
                    None 
                }
            }
        },
        false => {
            None
        }
    };

    // Initialize the camera
    let xclk = match server_info.capture_frames_at_once == 0 && ! operating_mode {
        true => 5000000,
        false => 25000000,
    };
    let cam = Camera::new(
        peripherals.pins.gpio48,    // XCLK
        peripherals.pins.gpio42,    // SIOD
        peripherals.pins.gpio41,    // SIOC
        peripherals.pins.gpio11,    // Y2
        peripherals.pins.gpio18,    // Y3
        peripherals.pins.gpio17,    // Y4
        peripherals.pins.gpio10,    // Y5
        peripherals.pins.gpio12,    // Y6
        peripherals.pins.gpio14,    // Y7
        peripherals.pins.gpio47,    // Y8
        peripherals.pins.gpio38,    // Y9
        peripherals.pins.gpio40,    // VSYNC
        peripherals.pins.gpio39,    // HREF
        peripherals.pins.gpio13,    // PCLK
        xclk,                       // XCLK frequency
        server_info.jpeg_quality as i32,   // JPEG quality
        2,                          // Frame buffer count (back to 2 for double buffering)
        camera::camera_grab_mode_t_CAMERA_GRAB_LATEST,        // grab mode
        //camera::camera_grab_mode_t_CAMERA_GRAB_WHEN_EMPTY,    // grab mode
        current_resolution,        // frame size have to be maximum resolution
    );
    let camera_device : Camera = match cam {
        Ok(cam) => {
            cam
        }
        Err(e) => {
            info!("Failed to initialize camera: {:?}", e);
            return Result::Err(anyhow::anyhow!("Failed to initialize camera"));
        }
    };

    let mut capture = Capture::new(camera_device, "/eMMC");
    capture.start();
    let monitoring_thread = Monitoring::new(config_data.model.clone(), config_data.api_key.clone());
    monitoring_thread.set_post_access_token(config_data.post_account.clone(),
        config_data.post_access_token.clone(), config_data.post_message_trigger.clone());
    monitoring_thread.set_storage_access_token(config_data.storage_account.clone(),
                                               config_data.storage_access_token.clone(),
                                               config_data.storage_signed_key.clone());
    monitoring_thread.set_last_posted_date_time(server_info.last_posted_date_time, server_info.post_interval);
    monitoring_thread.start();
    if operating_mode {
        unsafe { DEEP_SLEEP_AUTO_CAPTURE = false; }
        config_data.auto_capture = false;
        server_info.last_access_time = SystemTime::now();
        if server_enabled {
            server.as_mut().unwrap().set_server_info(server_info.clone());
        }
    }

    // led_ind.set_high().expect("Set indicator high failure");
    let mut one_shot = false;
    let mut movie_mode = false;
    let mut capture_indicator_on = false;
    let mut last_reconnect_time = SystemTime::now();
    loop {
        // imagefiles::list_files(Path::new("/eMMC"));
        if config_data.auto_capture || unsafe { DEEP_SLEEP_AUTO_CAPTURE } {
            server_info.capture_started = true;
        }
        // read battery voltage
        let battery_voltage : f32 =  adc.read(&mut adc_pin).unwrap() as f32 * 2.0 / 1000.0;

        if operating_mode {
            let rssi = wifi::get_rssi();
            if rssi == 0 {
                if  last_reconnect_time.elapsed().unwrap().as_secs() > 30 {
                    last_reconnect_time = SystemTime::now();
                    wifi_reconnect(&mut wifi_dev.as_mut().unwrap());
                }
            }
            if server_enabled {
                server.as_mut().unwrap().set_current_rssi(rssi);
                server.as_mut().unwrap().set_current_battery_voltage(battery_voltage);
                server_info = server.as_mut().unwrap().get_server_info().clone();
                one_shot = server.as_mut().unwrap().get_one_shot();
                // check save config
                if server_info.need_to_save {
                    server_info.need_to_save = false;
                    config_data.auto_capture = server_info.auto_capture;
                    config_data.duration = server_info.duration;
                    config_data.resolution = server_info.resolution;
                    config_data.track_id = server_info.track_id;
                    config_data.timezone_offset = server_info.timezone;
                    config_data.idle_in_sleep_time = server_info.idle_in_sleep_time;
                    config_data.query_openai = server_info.query_openai;
                    config_data.query_prompt = server_info.query_prompt.clone();
                    config_data.model = server_info.openai_model.clone();
                    config_data.autofocus_once = server_info.autofocus_once;
                    config_data.status_report = server_info.status_report;
                    config_data.status_report_interval = server_info.status_report_interval;
                    config_data.post_interval = server_info.post_interval;
                    config_data.leap_day = server_info.leap_time.day;
                    config_data.leap_hour = server_info.leap_time.hour;
                    config_data.leap_minute = server_info.leap_time.minute;
                    config_data.capture_frames_at_once = server_info.capture_frames_at_once;
                    config_data.overwrite_saved = server_info.overwrite_saved;
                    config_data.direct_write_mode = server_info.direct_write_mode;
                    config_data.jpeg_quality = server_info.jpeg_quality;
                    let save_config = config_data.get_all_config();
                    let toml_cfg = convert_config_to_toml_string(&save_config);
                    match nvs.set_str("config", toml_cfg.as_str()) {
                        Ok(_) => { info!("Save config"); },
                        Err(ref e) => { info!("Set default config failed {:?}", e); }
                    }
                    server.as_mut().unwrap().set_server_info(server_info.clone());
                }
                server.as_mut().unwrap().set_server_capture_started(server_info.capture_started);
            }
            current_duration = server_info.duration;
            if !server_info.capture_started {
                // when idle, check last access time
                if server_info.last_access_time.duration_since(UNIX_EPOCH).unwrap().as_millis() > 1700000000 {
                    let last_access_time = server_info.last_access_time.elapsed().unwrap().as_secs();
                    if last_access_time > config_data.idle_in_sleep_time as u64 {
                        operating_mode = false;
                        info!("Idle time {:?} over. Go to sleep", last_access_time);
                        emmc_cam_power.set_high().expect("Set emmc_cam_power high failure");
                        deep_and_light_sleep_start(SleepMode::SleepModeDeep, 0);
                    }
                }
            }    
        }
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

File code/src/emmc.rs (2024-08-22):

#![allow(dead_code)]

use log::info;
use std::ffi::c_void;
use esp_idf_sys::sdmmc_slot_config_t;
use esp_idf_sys::sdmmc_card_t;
use esp_idf_sys::sdmmc_host_t;
use esp_idf_hal::sys::{sdspi_device_config_t, spi_bus_config_t};
use anyhow::Result;

const SDMMC_HOST_SLOT_0 : i32 = 0;
const SDMMC_HOST_SLOT_1 : i32 = 1;
const SDMMC_SLOT_CONFIG_WIDTH_4 : u8 = 4;
const SDMMC_SLOT_CONFIG_WIDTH_8 : u8 = 8;
const SDMMC_SLOT_CONFIG_CLK : i32 = 21;
const SDMMC_SLOT_CONFIG_CMD : i32 = 45;
const SDMMC_SLOT_CONFIG_D0 : i32 = 4;
const SDMMC_SLOT_CONFIG_D1 : i32 = 5;
const SDMMC_SLOT_CONFIG_D2 : i32 = 6;
const SDMMC_SLOT_CONFIG_D3 : i32 = 7;
const SDMMC_SLOT_CONFIG_D4 : i32 = 8;
const SDMMC_SLOT_CONFIG_D5 : i32 = 3;
const SDMMC_SLOT_CONFIG_D6 : i32 = 46;
const SDMMC_SLOT_CONFIG_D7 : i32 = 9;
const SDMMC_HOST_FLAG_8BIT: u32 = 1 << 2;
const SDMMC_HOST_FLAG_4BIT: u32 = 1 << 1;
const SDMMC_HOST_FLAG_1BIT: u32 = 1 << 0;
const SDMMC_FREQ_52M: i32 = 52000;
const SDMMC_FREQ_30M: i32 = 30000;
const SDMMC_FREQ_10M: i32 = 10000;
const SDMMC_FREQ_2M: i32 = 2000;
const SDMMC_HOST_FLAG_DDR: u32 = 1 << 4;

// SDSPI HOST
const SPI_HOST_ID: i32 = 1;
const SDMMC_FREQ_DEFAULT: i32 = 20000;  // 20 MHz
const SDMMC_HOST_FLAG_SPI : u32 = 1 << 3;
const SDMMC_HOST_FLAG_DEINIT_ARG : u32 = 1 << 5;
const SDSPI_SLOT_CONFIG_CMD: i32 = 9;   // GPIO9 MOSI
const SDSPI_SLOT_CONFIG_CLK: i32 = 7;   // GPIO7 SCLK
const SDSPI_SLOT_CONFIG_D0: i32 = 8;    // GPIO8 MISO
const SDSPI_SLOT_CONFIG_CS: i32 = 21;   // GPIO21 CS

const VFS_MOUNT_ALLOC_UNIT_SIZE: usize = 32 * 1024;

const MOUNT_POINT : &[u8] = b"/eMMC\0";

pub struct SDSPIHost {
    host: *mut sdmmc_host_t,
    card: esp_idf_hal::sys::sdmmc_card_t,
    sdspi_config: sdspi_device_config_t,
    spi_bus_config: spi_bus_config_t,
}

impl SDSPIHost {
    pub fn new() -> SDSPIHost {
        SDSPIHost {
            host : Box::into_raw(Box::new(esp_idf_hal::sys::sdmmc_host_t {
                flags: SDMMC_HOST_FLAG_SPI | SDMMC_HOST_FLAG_DEINIT_ARG,
                slot: SPI_HOST_ID,
                max_freq_khz: SDMMC_FREQ_DEFAULT,        
                io_voltage: 3.3,
                init: Some(esp_idf_hal::sys::sdspi_host_init),
                set_bus_width: None,
                get_bus_width: None,
                set_bus_ddr_mode: None,
                set_card_clk: Some(esp_idf_hal::sys::sdspi_host_set_card_clk),
                set_cclk_always_on: None,
                do_transaction: Some(esp_idf_hal::sys::sdspi_host_do_transaction),
                io_int_enable: Some(esp_idf_hal::sys::sdspi_host_io_int_enable),
                io_int_wait: Some(esp_idf_hal::sys::sdspi_host_io_int_wait),
                command_timeout_ms: 0,
                get_real_freq: Some(esp_idf_hal::sys::sdspi_host_get_real_freq),
                input_delay_phase: 0,
                set_input_delay: Some(esp_idf_hal::sys::sdmmc_host_set_input_delay),
                __bindgen_anon_1: esp_idf_hal::sys::sdmmc_host_t__bindgen_ty_1 {
                    deinit_p: Some(esp_idf_hal::sys::sdspi_host_remove_device),
                },        
            })),
            card: esp_idf_hal::sys::sdmmc_card_t::default(),
            sdspi_config: esp_idf_sys::sdspi_device_config_t {
                host_id: SPI_HOST_ID as u32,
                gpio_cs: SDSPI_SLOT_CONFIG_CS,
                gpio_cd: -1,
                gpio_wp: -1,
                gpio_int: -1,
                gpio_wp_polarity: false },
            spi_bus_config: esp_idf_hal::sys::spi_bus_config_t {
                __bindgen_anon_1: esp_idf_hal::sys::spi_bus_config_t__bindgen_ty_1 {
                    mosi_io_num: SDSPI_SLOT_CONFIG_CMD,
                },
                __bindgen_anon_2: esp_idf_hal::sys::spi_bus_config_t__bindgen_ty_2 {
                    miso_io_num: SDSPI_SLOT_CONFIG_D0,
                },
                sclk_io_num: SDSPI_SLOT_CONFIG_CLK,
                __bindgen_anon_3: esp_idf_hal::sys::spi_bus_config_t__bindgen_ty_3 {
                    quadwp_io_num: -1,
                },
                __bindgen_anon_4: esp_idf_hal::sys::spi_bus_config_t__bindgen_ty_4 {
                    quadhd_io_num: -1,
                },
                data4_io_num: -1,
                data5_io_num: -1,
                data6_io_num: -1,
                data7_io_num: -1,
                max_transfer_sz: 4000,
                flags: 0,
                intr_flags: 0,
                isr_cpu_id: 0,
            },
        }
    }

    pub fn mount(&mut self) -> Result<(), anyhow::Error> {       
        let slot_config_ptr = &self.sdspi_config as *const sdspi_device_config_t;
        let mount_config = esp_idf_sys::esp_vfs_fat_sdmmc_mount_config_t {
            format_if_mount_failed: true,
            max_files: 5,
            allocation_unit_size: VFS_MOUNT_ALLOC_UNIT_SIZE,
            disk_status_check_enable: false,
        };

        let mut card_ptr = &mut self.card as *mut esp_idf_hal::sys::sdmmc_card_t;

        let mount_emmc = unsafe {
            let ret = esp_idf_hal::sys::spi_bus_initialize(
                SPI_HOST_ID as u32,
                &mut self.spi_bus_config,
                esp_idf_hal::sys::spi_common_dma_t_SPI_DMA_CH_AUTO
            );
            if ret != esp_idf_sys::ESP_OK {
                return Err(anyhow::anyhow!("Failed to initialize SPI bus"));
            }
            info!("spi_bus_initialize SPIxID: {}", SPI_HOST_ID);
            esp_idf_hal::sys::esp_vfs_fat_sdspi_mount(
                MOUNT_POINT.as_ptr() as *const i8,
                self.host,
                slot_config_ptr,
                &mount_config,
                &mut card_ptr,
            )
        };
        let mount_point_str = std::str::from_utf8(MOUNT_POINT).unwrap();
        match mount_emmc {
            esp_idf_sys::ESP_OK => {
                info!("SDSPI SD Card mounted successfully {:?}", mount_point_str);
                Ok(())
            }
            _ => {
                Err(anyhow::anyhow!("Failed to mount. {:?}", mount_point_str))
            }
        }
    }
    
    #[allow(dead_code)]
    pub fn format(&mut self) {
        info!("esp_vfs_fat_sdcard_format");
        let card_ptr = &mut self.card as *mut esp_idf_hal::sys::sdmmc_card_t;
        let format_emmc = unsafe {
            esp_idf_sys::esp_vfs_fat_sdcard_format(
                MOUNT_POINT.as_ptr() as *const i8,
                card_ptr,
            )
        };
        match format_emmc {
            esp_idf_sys::ESP_OK => {
                info!("SD card formatted successfully");
            }
            _ => {
                info!("Failed to format eMMC");
            }
        }
    }
}

pub struct EMMCHost {
    host: *mut sdmmc_host_t,
    card: *mut sdmmc_card_t,
    slot_config: sdmmc_slot_config_t,
}
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

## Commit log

2024-05-26 Change Regulator IC and Pullup R
    [esp32-cam-emmc.kicad_sch, qi-receiver.kicad_sch]
2024-05-30 add esp-camera-rs driver as submodule
2024-06-04 Fixed crash on boot
    [main.rs]
2024-06-04 Add README.md etc.
    [bom.csv, botom.stl, cap.stl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]
2024-06-06 Change reglator more low power
    [bom.csv]
2024-06-08 Add print ssid, ip address info.
2024-06-08 Change container
    [botom.stl, bottom-v9.stl, cap-v9.stl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]
2024-06-22 v0.2.0 version code and contaier
    [base-v14.stl, cap-v11.stl, top-v15.stl]
2024-08-25 Fixed count captured frames
    [main.rs]
2024-08-29 Fixed panic when wakeup from deep sleep
    [main.rs]
2024-09-01 Fixed the bug Drirect Write Mode switch can not changed on Capture menu.

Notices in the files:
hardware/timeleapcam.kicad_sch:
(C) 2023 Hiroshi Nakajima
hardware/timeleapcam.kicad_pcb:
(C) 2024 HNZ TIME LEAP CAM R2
